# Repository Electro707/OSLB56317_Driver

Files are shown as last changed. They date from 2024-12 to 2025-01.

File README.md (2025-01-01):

# OSLB56317-XX LED Driver

This project is to drive the OSLB56317 16x16 LED matrix I got from my trip to Japan (from [Akizuki](https://maps.app.goo.gl/3vW3UY29P5pvr1BS6))

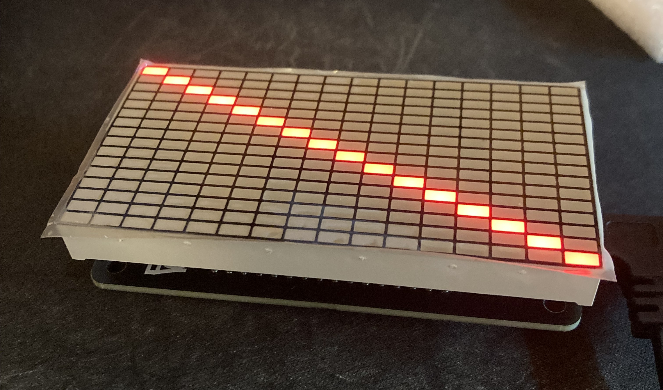
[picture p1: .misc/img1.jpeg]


# Project Structure
- `CAD`: FreeCAD Source file for enclosure
- `Firmware_Demo`: A quick demo firmware to get the display up and running
- `Firmware_FFT`: Firmware to display an audio spectrograph from a USB host
    - The firmware will act as a USB speaker, which audio must be routed to it
- `PCB`: KiCAD PCB source files

# Known Issues
- I goofed up on the RP2040's SPI wiring to the constant current led driver, so for now it is emulated in software
    - todo: make this a PIO block, or even a PIO block to drive the entire display?
- In the CAD file, there is no easy way to take it apart other than pushing a small flat head between the display and the case. With PLA, the case is maluable enough to bend
    - todo: add some small slot eventually to be able to easily remove the display assembly
- In the schematic, the columns and row new names should be swapped (don't ask how that happened), but this has no effects on functionality
- In `Firmware_FFT`, every now and then the main loop will unexpectantly stop, randomly
    - todo: attach debugger and see what causes this crash, probably some incorrect memory indexing
    
# todo, maybe
- [ ] Develop a PIO block for the LED matrix
- [ ] Create more fun demo codes (animation?)
- [x] Create a USB audio spectrum analyzer

# License
This project, except for the external [Firmware_FFT/Adafruit_ZeroFFT](Firmware_FFT/Adafruit_ZeroFFT), is licensed under GPLv3. See [LICENSE.md](LICENSE.md) for details.

# Credit
A fork of [Adafruit's ZeroFFT library, by donmccoy](https://github.com/donmccoy/Adafruit_ZeroFFT/tree/bugfix), was used in this project, and that is licensed under BSD-3

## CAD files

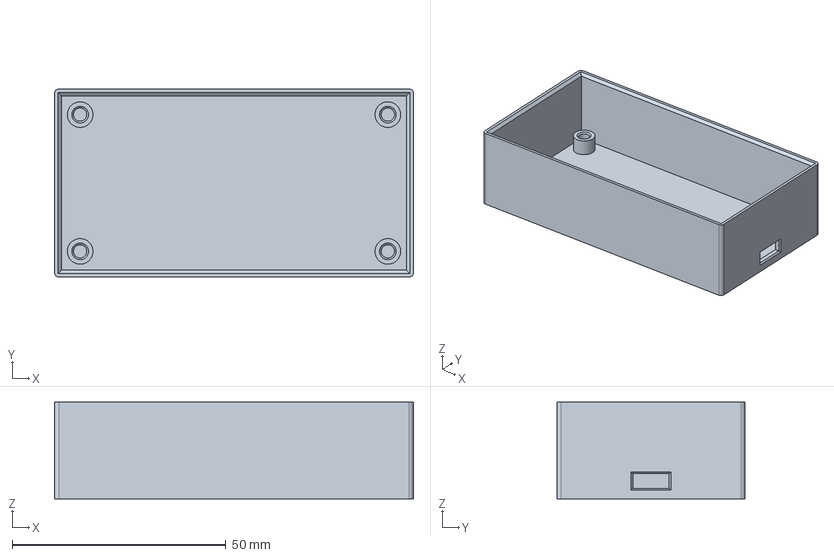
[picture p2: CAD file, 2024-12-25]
CAD/Bottom.FCStd
84.0 x 44.0 x 22.6 mm

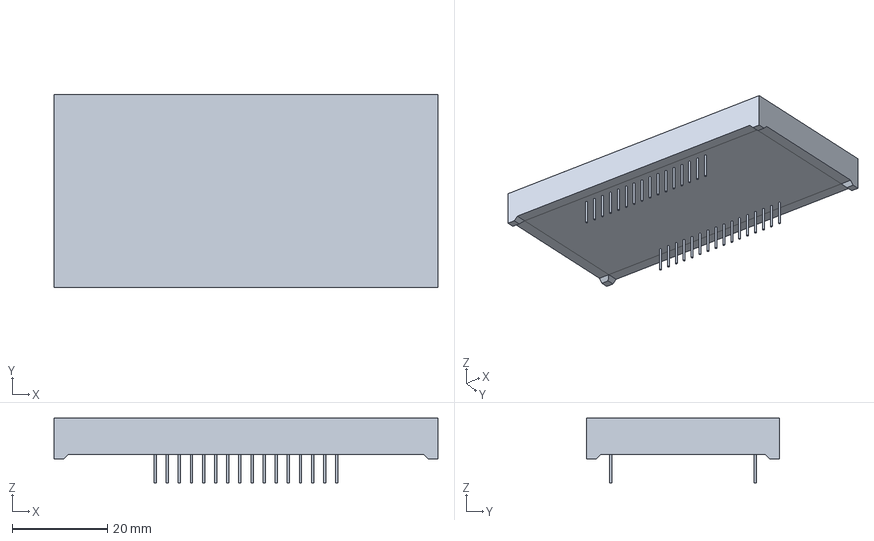
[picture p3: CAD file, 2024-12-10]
PCB/3D-Source-FreeCAD/OSLB56317_CAD_Model.FCStd
80.5 x 40.5 x 13.6 mm

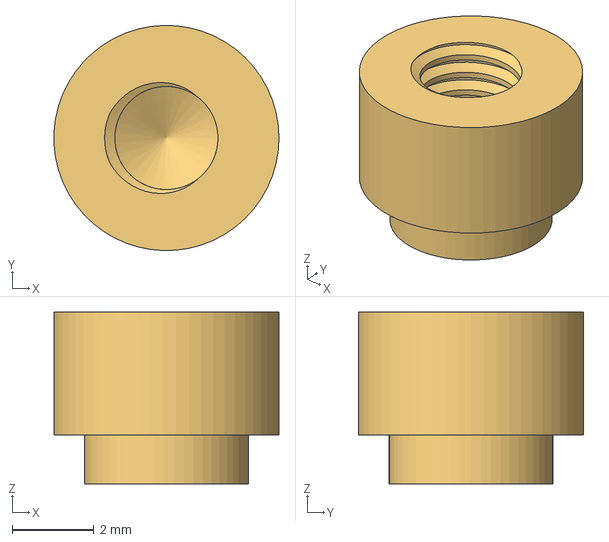
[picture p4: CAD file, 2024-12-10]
PCB/M3_Standoff.step
5.50 x 5.50 x 4.20 mm

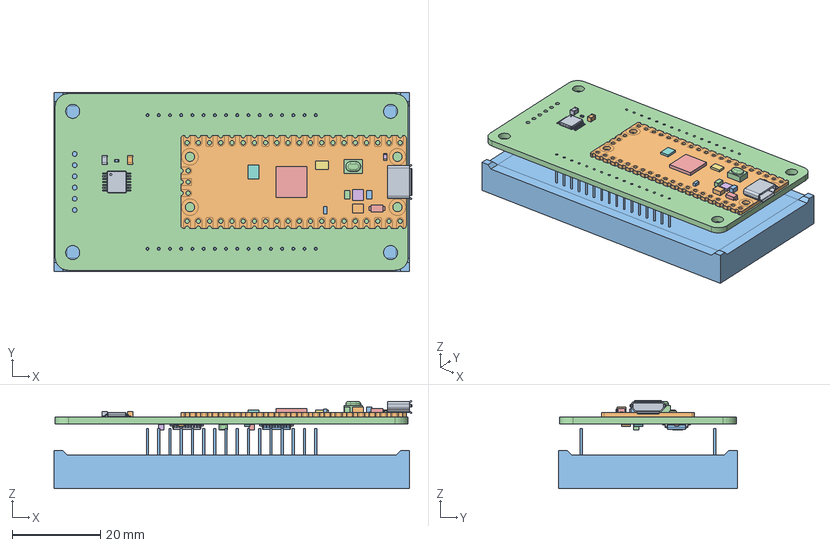
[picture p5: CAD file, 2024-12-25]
CAD/PCB.FCStd
81.1 x 40.5 x 20.0 mm
TSSOP_14_44x5mm_P065mm
RaspberryPi_Pico_Compound
RaspberryPi_Pico_Compound001
RaspberryPi_Pico_Compound002
RaspberryPi_Pico_Compound003
RaspberryPi_Pico_Compound004
RaspberryPi_Pico_Compound005
RaspberryPi_Pico_Compound006
RaspberryPi_Pico_Compound007
RaspberryPi_Pico_Compound008
RaspberryPi_Pico_Compound009
RaspberryPi_Pico_Compound010
RaspberryPi_Pico_Compound011
RaspberryPi_Pico_Compound012
RaspberryPi_Pico_Compound013
RaspberryPi_Pico_Compound014
C_0805_2012Metric
C_0805_2012Metric002
R_0402_1005Metric
C_0805_2012Metric004
C_0805_2012Metric006
C_0805_2012Metric008
R_0402_1005Metric002
R_0805_2012Metric
TSSOP_20_44x65mm_P065mm
R_0402_1005Metric004
R_0402_1005Metric006
R_0402_1005Metric008
R_0402_1005Metric010
R_0402_1005Metric012
R_0402_1005Metric014
R_0402_1005Metric016
R_0402_1005Metric018
R_0805_2012Metric002
R_0402_1005Metric020
R_0402_1005Metric022
R_0402_1005Metric024
R_0402_1005Metric026
R_0402_1005Metric028
R_0402_1005Metric030
R_0402_1005Metric032
TSSOP_20_44x65mm_P065mm001
OSLB56317-XX Driver_PCB

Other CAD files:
CAD/Assy.FCStd
PCB/OSLB56317_CAD_Model-Body.step
PCB/3D-Source-FreeCAD/M3_Standoff.FCStd

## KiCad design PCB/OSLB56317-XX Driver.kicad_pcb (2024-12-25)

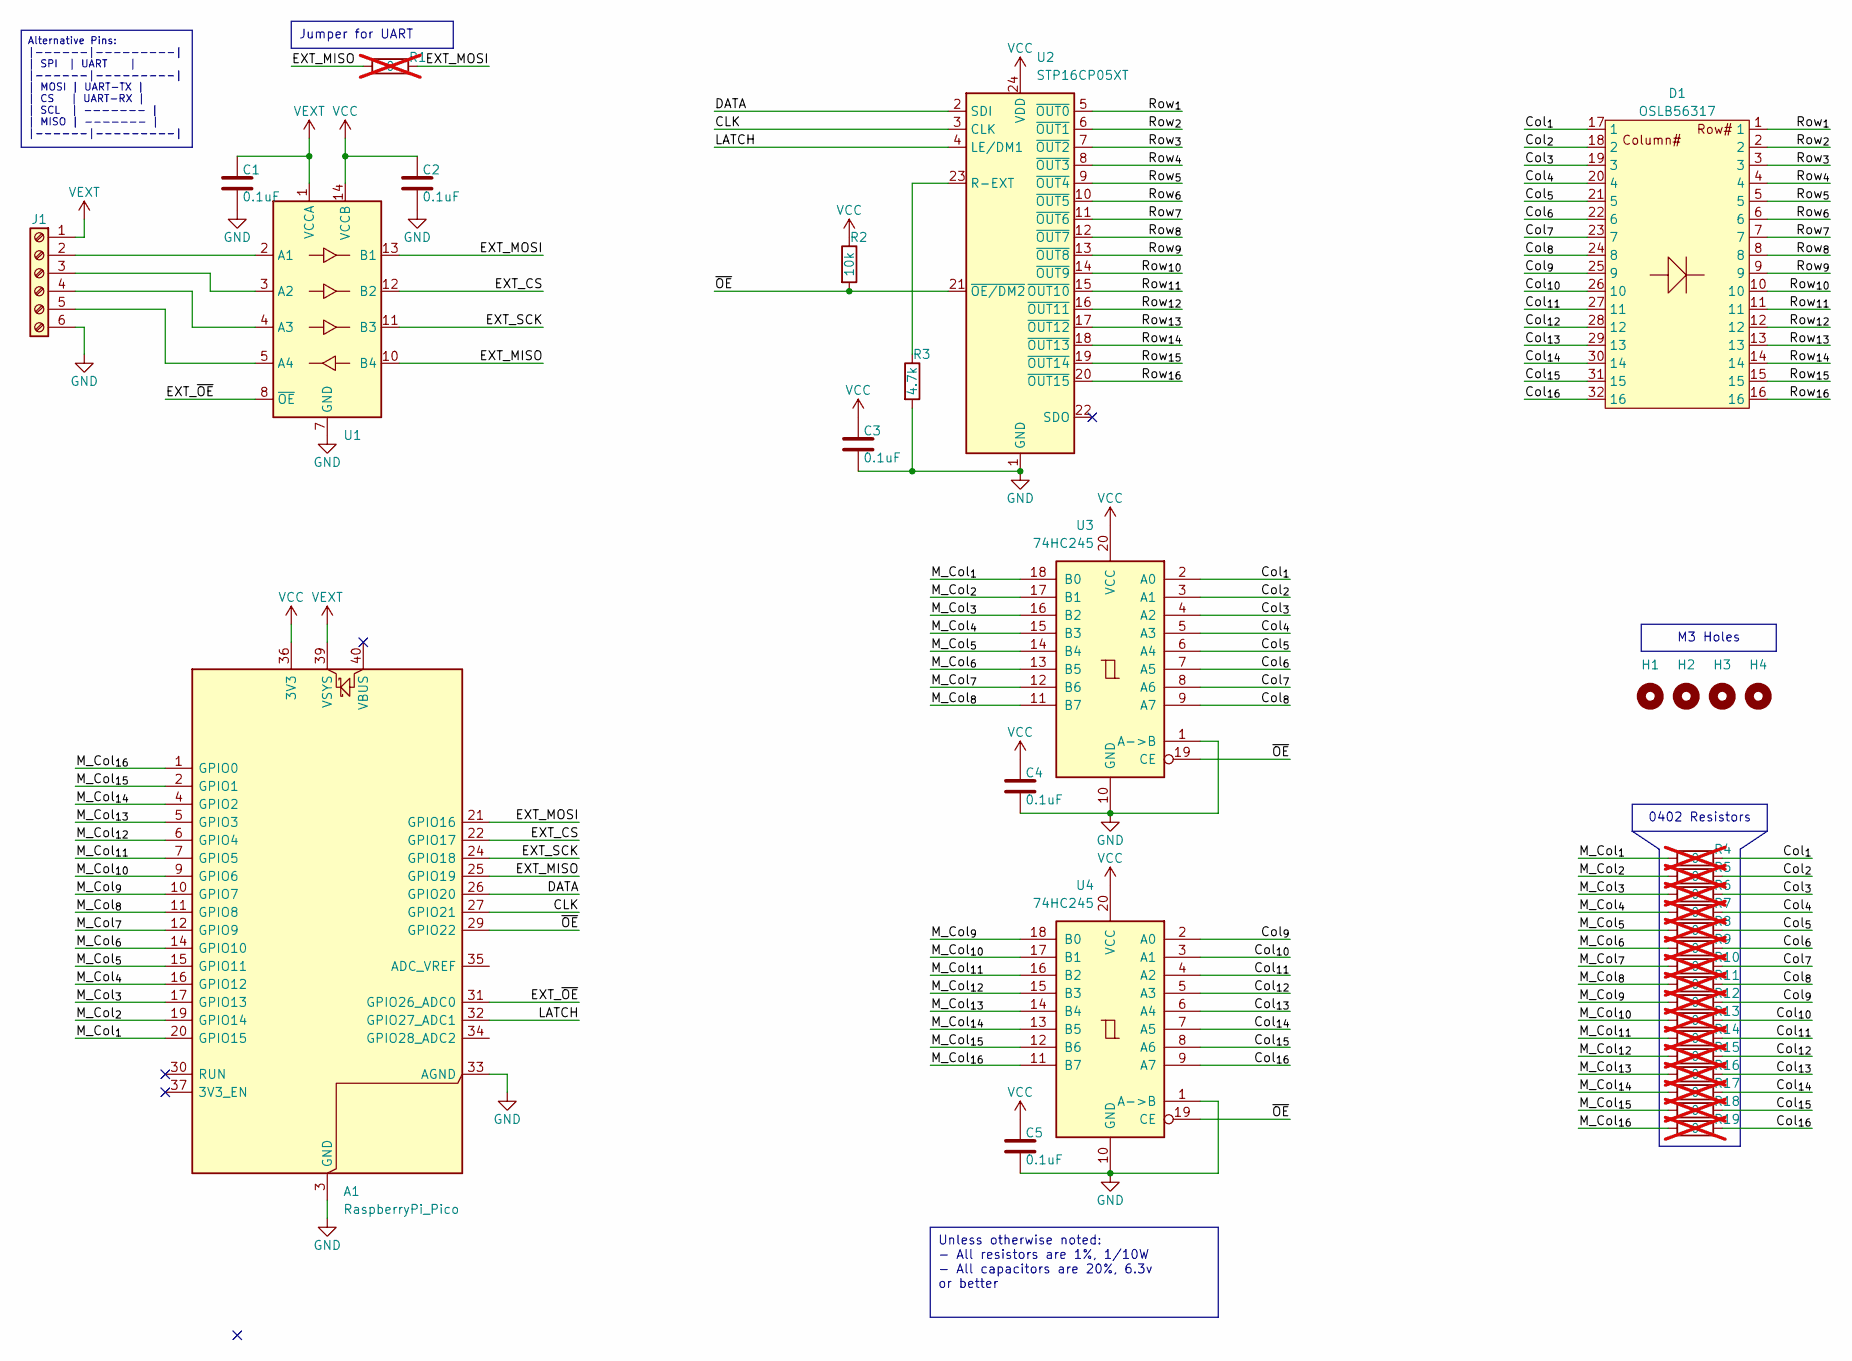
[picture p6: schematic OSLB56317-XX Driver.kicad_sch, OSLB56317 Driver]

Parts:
A1: RaspberryPi_Pico; RaspberryPi_Pico_Original_SMD_HandSolder
C1, C2, C3, C4, C5: 0.1uF; C_0805_2012Metric
D1: OSLB56317; OSLB56317-XX
H1, H2, H3, H4: MountingHole_Pad; MountingHole_3.2mm_M3
J1: Screw_Terminal_01x06; TerminalBlock_Phoenix_MPT-0,5-6-2.54_1x06_P2.54mm_Horizontal
R1, R4, R5, R6, R7, R8, R9, R10, R11, R12, R13, R14, R15, R16, R17, R18, R19: 0; R_0402_1005Metric; not fitted
R2: 10k; R_0805_2012Metric
R3: 4.7k; R_0805_2012Metric
U1: TSSOP-14_4.4x5mm_P0.65mm
U2: STP16CP05XT; HTSSOP-24-1EP_4.4x7.8mm_P0.65mm_EP3.2x5mm
U3, U4: 74HC245; TSSOP-20_4.4x6.5mm_P0.65mm

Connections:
/CLK: A1.27 (GPIO21), U2.3 (CLK)
/Col_{1}: D1.17 (1), R4.2, U3.2 (A0)
/Col_{2}: D1.18 (2), R5.2, U3.3 (A1)
/Col_{3}: D1.19 (3), R6.2, U3.4 (A2)
/Col_{4}: D1.20 (4), R7.2, U3.5 (A3)
/Col_{5}: D1.21 (5), R8.2, U3.6 (A4)
/Col_{6}: D1.22 (6), R9.2, U3.7 (A5)
/Col_{7}: D1.23 (7), R10.2, U3.8 (A6)
/Col_{8}: D1.24 (8), R11.2, U3.9 (A7)
/Col_{9}: D1.25 (9), R12.2, U4.2 (A0)
/Col_{10}: D1.26 (10), R13.2, U4.3 (A1)
/Col_{11}: D1.27 (11), R14.2, U4.4 (A2)
/Col_{12}: D1.28 (12), R15.2, U4.5 (A3)
/Col_{13}: D1.29 (13), R16.2, U4.6 (A4)
/Col_{14}: D1.30 (14), R17.2, U4.7 (A5)
/Col_{15}: D1.31 (15), R18.2, U4.8 (A6)
/Col_{16}: D1.32 (16), R19.2, U4.9 (A7)
/DATA: A1.26 (GPIO20), U2.2 (SDI)
/EXT_CS: A1.22 (GPIO17), U1.12 (B2)
/EXT_MISO: A1.25 (GPIO19), R1.1, U1.10 (B4)
/EXT_MOSI: A1.21 (GPIO16), R1.2, U1.13 (B1)
/EXT_SCK: A1.24 (GPIO18), U1.11 (B3)
/EXT_~OE: A1.31 (GPIO26_ADC0), U1.8 (~OE)
/LATCH: A1.32 (GPIO27_ADC1), U2.4 (LE/DM1)
/M_Col_{1}: A1.20 (GPIO15), R4.1, U3.18 (B0)
/M_Col_{2}: A1.19 (GPIO14), R5.1, U3.17 (B1)
/M_Col_{3}: A1.17 (GPIO13), R6.1, U3.16 (B2)
/M_Col_{4}: A1.16 (GPIO12), R7.1, U3.15 (B3)
/M_Col_{5}: A1.15 (GPIO11), R8.1, U3.14 (B4)
/M_Col_{6}: A1.14 (GPIO10), R9.1, U3.13 (B5)
/M_Col_{7}: A1.12 (GPIO9), R10.1, U3.12 (B6)
/M_Col_{8}: A1.11 (GPIO8), R11.1, U3.11 (B7)
/M_Col_{9}: A1.10 (GPIO7), R12.1, U4.18 (B0)
/M_Col_{10}: A1.9 (GPIO6), R13.1, U4.17 (B1)
/M_Col_{11}: A1.7 (GPIO5), R14.1, U4.16 (B2)
/M_Col_{12}: A1.6 (GPIO4), R15.1, U4.15 (B3)
/M_Col_{13}: A1.5 (GPIO3), R16.1, U4.14 (B4)
/M_Col_{14}: A1.4 (GPIO2), R17.1, U4.13 (B5)
/M_Col_{15}: A1.2 (GPIO1), R18.1, U4.12 (B6)
/M_Col_{16}: A1.1 (GPIO0), R19.1, U4.11 (B7)
/Row_{1}: D1.1, U2.5 (~OUT0)
/Row_{2}: D1.2, U2.6 (~OUT1)
/Row_{3}: D1.3, U2.7 (~OUT2)
/Row_{4}: D1.4, U2.8 (~OUT3)
/Row_{5}: D1.5, U2.9 (~OUT4)
/Row_{6}: D1.6, U2.10 (~OUT5)
/Row_{7}: D1.7, U2.11 (~OUT6)
/Row_{8}: D1.8, U2.12 (~OUT7)
/Row_{9}: D1.9, U2.13 (~OUT8)
/Row_{10}: D1.10, U2.14 (~OUT9)
/Row_{11}: D1.11, U2.15 (~OUT10)
/Row_{12}: D1.12, U2.16 (~OUT11)
/Row_{13}: D1.13, U2.17 (~OUT12)
/Row_{14}: D1.14, U2.18 (~OUT13)
/Row_{15}: D1.15, U2.19 (~OUT14)
/Row_{16}: D1.16, U2.20 (~OUT15)
/~OE: A1.29 (GPIO22), R2.2, U2.21 (~OE/DM2), U3.19 (CE), U4.19 (CE)
GND: A1.3 (GND), A1.8 (GND), A1.13 (GND), A1.18 (GND), A1.23 (GND), A1.28 (GND), A1.33 (AGND), A1.38 (GND), C1.2, C2.2, C3.2, C4.2, C5.2, J1.6, R3.2, U1.7 (GND), U2.1 (GND), U2.25 (GND), U3.1 (A->B), U3.10 (GND), U4.1 (A->B), U4.10 (GND)
unnamed: J1.2, U1.2 (A1)
unnamed: J1.3, U1.3 (A2)
unnamed: J1.4, U1.4 (A3)
unnamed: J1.5, U1.5 (A4)
unnamed: R3.1, U2.23 (R-EXT)
VCC: A1.36 (3V3), C2.1, C3.1, C4.1, C5.1, R2.1, U1.14 (VCCB), U2.24 (VDD), U3.20 (VCC), U4.20 (VCC)
VEXT: A1.39 (VSYS), C1.1, J1.1, U1.1 (VCCA)

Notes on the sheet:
M3 Holes
Alternative Pins: |------|---------| | SPI | UART | |------|---------| | MOSI | UART-TX | | CS | UART-RX | | SCL | ------- | | MISO | ------- | |------|---------|
Unless otherwise noted: - All resistors are 1%, 1/10W - All capacitors are 20%, 6.3v or better
0402 Resistors
Jumper for UART

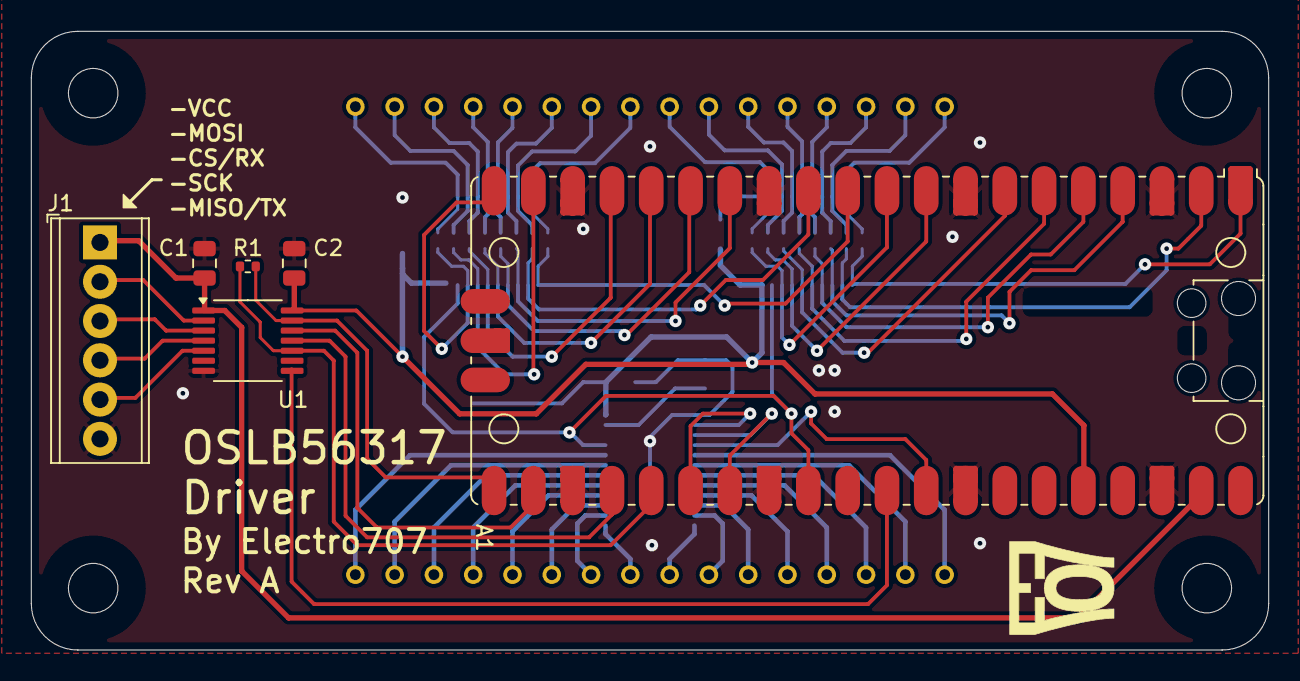
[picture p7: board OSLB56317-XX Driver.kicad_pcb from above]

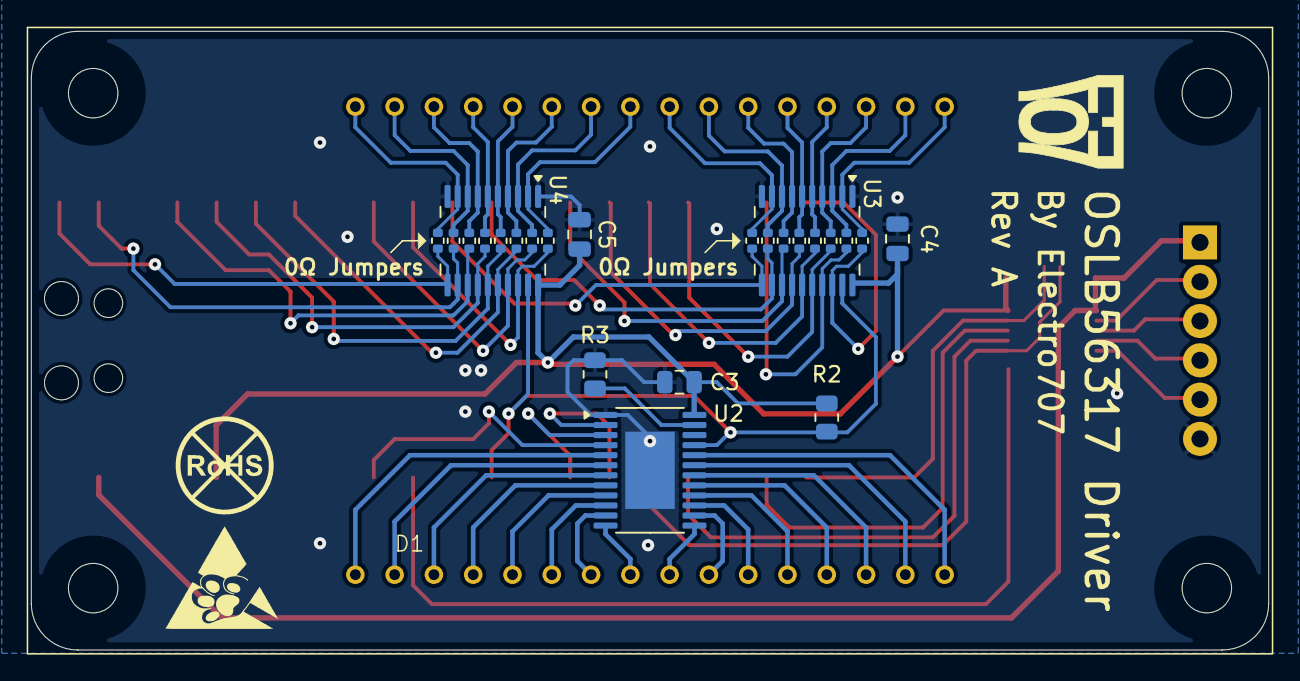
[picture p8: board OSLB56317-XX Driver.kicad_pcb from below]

Board: 2 copper layers, 80.0 x 40.0 mm, 35 parts (25 on the bottom side), 65 nets.

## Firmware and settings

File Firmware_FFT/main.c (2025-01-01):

#include <stdio.h>
#include "pico/stdlib.h"
#include "hardware/pwm.h"
#include "hardware/irq.h"

#include "tusb.h"

#include "Adafruit_ZeroFFT.h"
#include "fftBin.h"
#include "usbHandler.h"

#include "defines.h"

void processAudioFFT(void);
void setColData(uint16_t toWrite);
void transpose(uint16_t *from, uint16_t *to);
void updateDisplay(void);
void pwmIrq(void);

uint16_t prevFilterData[16] = {0};          // buffer if previous filterbank result (range 0 to 16)
uint16_t dispFrameBuff[2][16] = {0};        // the display framebuffer as a swapping double buffer
uint8_t currDisp = 0;                       // index of the active display in the double buffer
uint8_t newDispRdy = 0;                     // flag to set whether the new framebuffer is ready to use

int main()
{
    usbInit();

    gpio_set_function(PIN_DATA,      GPIO_FUNC_SIO);
    gpio_set_function(PIN_SCK,       GPIO_FUNC_SIO);
    gpio_set_function(PIN_OE,        GPIO_FUNC_SIO);
    gpio_set_function(PIN_LATCH,     GPIO_FUNC_SIO);
    gpio_set_function_masked(0xFFFF, GPIO_FUNC_SIO);

    gpio_set_dir_out_masked(0xFFFF);

    gpio_put(PIN_LATCH, 0);
    gpio_put(PIN_OE, 1);

    gpio_set_dir(PIN_LATCH, GPIO_OUT);
    gpio_set_dir(PIN_OE, GPIO_OUT);
    gpio_set_dir(PIN_DATA, GPIO_OUT);
    gpio_set_dir(PIN_SCK, GPIO_OUT);

    pwm_clear_irq(PWM_LED_SLICE);
    pwm_set_clkdiv_int_frac4(PWM_LED_SLICE, 8, 0);
    pwm_set_wrap(PWM_LED_SLICE, 7875-1);
    pwm_set_irq_enabled(PWM_LED_SLICE, true);
    pwm_set_enabled(PWM_LED_SLICE, true);

    gpio_put(PIN_OE, 1);
    setColData(0);
    gpio_put_masked(0xFFFF, 0); 
    gpio_put(PIN_OE, 0);

    irq_set_exclusive_handler(PWM_IRQ_WRAP, pwmIrq);
    irq_set_priority(PWM_IRQ_WRAP, 0);
    irq_set_priority(USBCTRL_IRQ, 10);
    
    irq_set_enabled(PWM_DEFAULT_IRQ_NUM(), true);

    while(true) {
        tud_task();             // TinyUSB device task
        processAudioFFT();      // Process received audio data (if any)
    }
}

void setColData(uint16_t toWrite){
    // software SPI, because I screwed up on pin layout :P
    // probably can be moved to a PIO block, to investigate
    gpio_put(PIN_LATCH, 0);
    for(int i=0;i<16;i++){
        gpio_put(PIN_DATA, toWrite & 1);
        toWrite >>= 1;
        gpio_put(PIN_SCK, 1);
        sleep_us(1);
        gpio_put(PIN_SCK, 0);
        sleep_us(1);
    }
    gpio_put(PIN_LATCH, 1);
}

// quick function to transpose a matrix, to turn from column to row index
void transpose(uint16_t *from, uint16_t *to){
    for (int i = 0; i < 16; i++) {
      to[i] = 0;
      for (int j = 0; j < 16; j++) {
        to[i] <<= 1;
        to[i] |= (from[15-j] & (1 << i)) ? 1 : 0;
      }
    }
}

void processAudioFFT(void){
    uint16_t stat;
    static uint16_t fftData[FFT_SIZE];
    static uint16_t newFiltData[16];
    
    if(tud_audio_available() >= (FFT_SIZE*2)){
        stat = tud_audio_read(fftData, FFT_SIZE*2);
        if(stat != FFT_SIZE*2){
            sentString("ERROR: Read != FFT_SIZE\n");;
            return;
        }

        stat = ZeroFFTMagnitude(fftData, FFT_SIZE, false);
        if(stat != 0){
            sentString("ERROR: fft failed\n");
            return;
        }

        if(newDispRdy){
            sentString("ERR: overrun\n");
            return;
        }

        binFFT(fftData, newFiltData);

        // software peak detector with a bleed of -2 per calculation, and to copy the
        // new filter bank to the global previous filter bank
        for(int i=0;i<16;i++){
            // only do something if the last filter value is not zero
            if(prevFilterData[i]){
                // bleed
                if(prevFilterData[i] <= BLEED_VALUE){
                    prevFilterData[i] = 0;
                } else {
                    prevFilterData[i] -= BLEED_VALUE;    
                }

                // if the previous filter is greater than the current one, set current to old one (after -1)
                if(prevFilterData[i] > newFiltData[i]){
                    newFiltData[i] = prevFilterData[i];
                }
            }
            // update previous filter to the current one
            prevFilterData[i] = newFiltData[i];
            // now we convert the filter numerical value to number of 1's enabled (so 4 is actually 15)
            newFiltData[i] = (1 << newFiltData[i]) - 1;
        }
        
        // transpose the fiter data to the display buffer, as the rows and columns index are flipped
        uint16_t *nextDispBuff = dispFrameBuff[(currDisp + 1) & 0x1];
        transpose(newFiltData, nextDispBuff);
        // declare to the interrupt that the new display buffer is ready
        newDispRdy = 1;
    }
}

// function to update display, called by a pwm interrupt every 500uS
void updateDisplay(void){
    static uint8_t row = 0;
    uint16_t toDisp;

    // only update current display shown when we are ready, and we are starting a new row
    if(newDispRdy & (row == 0)){
        currDisp++;
        currDisp &= 1;
        newDispRdy = 0;
    }

    toDisp = dispFrameBuff[currDisp][row];

    // gpio_put(PIN_OE, 1);                    // turn off the display while updating (doesn't seem nessesary)
    setColData(toDisp);                        // update the column data
    gpio_put_masked(0xFFFF, 1 << row);         // set the appropriate row
    // gpio_put(PIN_OE, 0);

    // increment row from 0 to 15
    row++;
    row &= 0xF;
}

// interrupt entry point
void pwmIrq(void){
    if(pwm_get_irq_status_mask() & (1<<PWM_LED_SLICE)){
        updateDisplay();
        pwm_clear_irq(PWM_LED_SLICE);
    }
}

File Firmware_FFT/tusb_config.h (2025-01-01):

/*
 * The MIT License (MIT)
 *
 * Copyright (c) 2019 Ha Thach (tinyusb.org)
 *
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
 */

#ifndef _TUSB_CONFIG_H_
#define _TUSB_CONFIG_H_

#ifdef __cplusplus
 extern "C" {
#endif

#include "usb_descriptors.h"

//--------------------------------------------------------------------+
// Board Specific Configuration
//--------------------------------------------------------------------+

// RHPort number used for device can be defined by board.mk, default to port 0
#ifndef BOARD_TUD_RHPORT
#define BOARD_TUD_RHPORT      0
#endif

// RHPort max operational speed can defined by board.mk
#ifndef BOARD_TUD_MAX_SPEED
#define BOARD_TUD_MAX_SPEED   OPT_MODE_DEFAULT_SPEED
#endif

//--------------------------------------------------------------------
// COMMON CONFIGURATION
//--------------------------------------------------------------------

// defined by compiler flags for flexibility
#ifndef CFG_TUSB_MCU
#error CFG_TUSB_MCU must be defined
#endif

#ifndef CFG_TUSB_OS
#define CFG_TUSB_OS           OPT_OS_NONE
#endif

#ifndef CFG_TUSB_DEBUG
#define CFG_TUSB_DEBUG        0
#endif

// Enable Device stack
#define CFG_TUD_ENABLED       1

// Default is max speed that hardware controller could support with on-chip PHY
#define CFG_TUD_MAX_SPEED     BOARD_TUD_MAX_SPEED

#define CFG_TUSB_RHPORT0_MODE   (OPT_MODE_DEVICE)

/* USB DMA on some MCUs can only access a specific SRAM region with restriction on alignment.
 * Tinyusb use follows macros to declare transferring memory so that they can be put
 * into those specific section.
 * e.g
 * - CFG_TUSB_MEM SECTION : __attribute__ (( section(".usb_ram") ))
 * - CFG_TUSB_MEM_ALIGN   : __attribute__ ((aligned(4)))
 */
#ifndef CFG_TUSB_MEM_SECTION
#define CFG_TUSB_MEM_SECTION
#endif

#ifndef CFG_TUSB_MEM_ALIGN
#define CFG_TUSB_MEM_ALIGN          __attribute__ ((aligned(4)))
#endif

//--------------------------------------------------------------------
// DEVICE CONFIGURATION
//--------------------------------------------------------------------

#ifndef CFG_TUD_ENDPOINT0_SIZE
#define CFG_TUD_ENDPOINT0_SIZE    64
#endif

//------------- CLASS -------------//
#define CFG_TUD_CDC               1
#define CFG_TUD_AUDIO             1


//--------------------------------------------------------------------
// AUDIO DRIVER CONFIGURATION
//--------------------------------------------------------------------
#define CFG_TUD_AUDIO_FUNC_1_SAMPLE_RATE                              48000

#define CFG_TUD_AUDIO_FUNC_1_DESC_LEN                                 TUD_AUDIO_SPEAKER_MONO_FB_DESC_LEN
#define CFG_TUD_AUDIO_FUNC_1_N_AS_INT                                 1                                       // Number of Standard AS Interface Descriptors (4.9.1) defined per audio function - this is required to be able to remember the current alternate settings of these interfaces - We restrict us here to have a constant number for all audio functions (which means this has to be the maximum number of AS interfaces an audio function has and a second audio function with less AS interfaces just wastes a few bytes)
#define CFG_TUD_AUDIO_FUNC_1_CTRL_BUF_SZ                              64                                      // Size of control request buffer

#define CFG_TUD_AUDIO_ENABLE_EP_OUT                                   1
#define CFG_TUD_AUDIO_FUNC_1_N_BYTES_PER_SAMPLE_RX                    2
#define CFG_TUD_AUDIO_FUNC_1_RESOLUTION_RX                           16
#define CFG_TUD_AUDIO_FUNC_1_N_CHANNELS_RX                            1

#define CFG_TUD_AUDIO_FUNC_1_MAX_SAMPLE_RATE                         48000

#define CFG_TUD_AUDIO_FUNC_1_EP_OUT_SZ_MAX        TUD_AUDIO_EP_SIZE(CFG_TUD_AUDIO_FUNC_1_MAX_SAMPLE_RATE, CFG_TUD_AUDIO_FUNC_1_N_BYTES_PER_SAMPLE_RX, CFG_TUD_AUDIO_FUNC_1_N_CHANNELS_RX)
// #define CFG_TUD_AUDIO_FUNC_1_EP_OUT_SZ_MAX        1024
// #define CFG_TUD_AUDIO_FUNC_1_EP_OUT_SW_BUF_SZ     (TUD_OPT_HIGH_SPEED ? 32 : 4) * CFG_TUD_AUDIO_FUNC_1_EP_OUT_SZ_MAX // Example read FIFO every 1ms, so it should be 8 times larger for HS device

// we set the buffer to multiple, allowing to stack up until FFT is ready
#define CFG_TUD_AUDIO_FUNC_1_EP_OUT_SW_BUF_SZ     2048  // Example read FIFO every 1ms, so it should be 8 times larger for HS device

#define CFG_TUD_AUDIO_ENABLE_FEEDBACK_EP                             1

//--------------------------------------------------------------------
// CDC CLASS DRIVER CONFIGURATION
//--------------------------------------------------------------------

// CDC FIFO size of TX and RX
#define CFG_TUD_CDC_RX_BUFSIZE                    64
#define CFG_TUD_CDC_TX_BUFSIZE                    1024

#ifdef __cplusplus
 }
#endif

#endif /* _TUSB_CONFIG_H_ */

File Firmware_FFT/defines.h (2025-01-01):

/**
 * A list with common defines
 */

#ifndef _COMMON_H
#define _COMMON_H

#define BLEED_VALUE 2       // how many segments to subtract per cycle, a cycle being when we get FFT_SIZE audio data (~6mS)

#define FFT_BIN_SHIFT 5     // after binning the FFT, how much to right-shift the result by

// pin definitions
#define PIN_SCK     21
#define PIN_DATA    20
#define PIN_OE      22
#define PIN_LATCH   27

// the FFT size to use
#define FFT_SIZE    512

// the PWM slice that is used for the real-time interrupt
#define PWM_LED_SLICE 0

#endif

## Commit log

2024-12-10 Initial Release
    [M3_Standoff.FCStd, M3_Standoff.step, OSLB56317-XX Driver.kicad_pcb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]
2024-12-25 Added some CAD files
    [Assy.FCStd, Bottom.FCStd, OSLB56317-XX Driver.kicad_pcb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]
2024-12-25 Added CAD file note in readme
